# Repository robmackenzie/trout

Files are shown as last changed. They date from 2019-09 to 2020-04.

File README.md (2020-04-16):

# Magic Trout Imaginarium V2
ESP8266 based controller for talking/singing trout.

This is a fork of a previous project that ran the same idea off a raspberry pi controller. Here we have a perfboard with an mp3 module and the motor controllers all in one.

The board takes 12v, and can be run off pretty much any 12v battery or power source. It draws 1 amp at max load when talking.

The 
# Structure
## Docs
I've included all the PDFs for the components on the board, except for a generic 5v regulator that powers the hbridge and the audio chip.

## Audio/sd_card
The audio files which are included on the SD card on the mp3 player inside the control box. More can be added, which will be randomly chosen when the button is pushed.
Files must be be contained in SD card in specific structure.
The welcome file must be in the root directory, and be the first file coppied
onto the SD card. If you want to replace it, you must delete all other files
first. The files to be randomly chosen at a button push must be in a folder
called "02"
Example below:
/001.mp3 *Welcome file
/02/001.mp3 *Random file
/02/002.mp3 *Random file
/02/003.mp3 *Random file

## lib
External libraries that are used to control the trout, such as timing and mp3 player control. These are automatically pulled in with platform.io

## src
Source code that controls the fish. Inside the main.cpp file you can find adjustable variables to control timings of the fish.

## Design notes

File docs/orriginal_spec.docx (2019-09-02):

# Fortune Telling Fish.

A weird fish oracle that you can ask your fortune!

Trout which answers questions similar to a magic eight ball. Using a microcontroller similar to an Arduino called a propeller we can store many minutes of audio on an SD card and record the responses and lipsync the fish so that the responses and fish mouth match.

Possible additional features

- respond to sound with microphone. It would be ideal to be able to understand human speech but without a semi-powerful computer and internet, this would be difficult. If we wanted to use an internet connected Raspberry Pi this could be possible to some degree. For the standalone micro version, it would just respond to audio volume mainly and come to life and/or say something.
- Remote operation. Puppet the fish remotely! Using a camera and a microphone to give you fish telepresence. We would use a voice changer to make the fish voice. Essentially a puppet, it could be quite entertaining.
- Ask a question then touch the fish...or like press a button or touch a crystal ball....something that would trigger the response easier. Easier design
- wearable version! Mounted on your body in some form. Details to be determined. Need some sketches. (even crude is fine)

Mounting

Zee wants it to be sort of mounted in a tri-fold cabinet so when you approach it like a space you are entering...maybe install some lights. (Need illustration - crude is fine. I can fix them up)

Dates: End of June or June 11th for Maker Faire.

Fish measurements.

Nose to tail 29 cm

Dorsal fin tallest point 12 cm

Tail fin 8.5 cm

Kinda like this is s tent although this pic doesn't have the button

In a tent like A circus sideshow

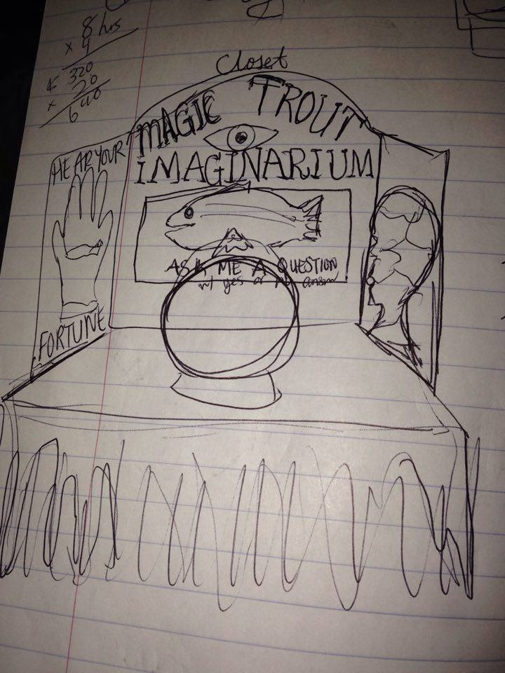
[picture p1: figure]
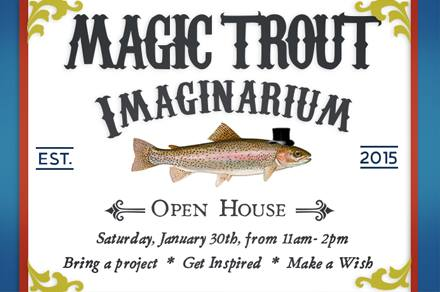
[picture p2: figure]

The button could be On the plaque.. I could make a new plaque if the one that it comes on isn't big enough, I could router out a place to fit the electronics in the back

New feature. Coin operation! Something like the following unit taking a loonie?

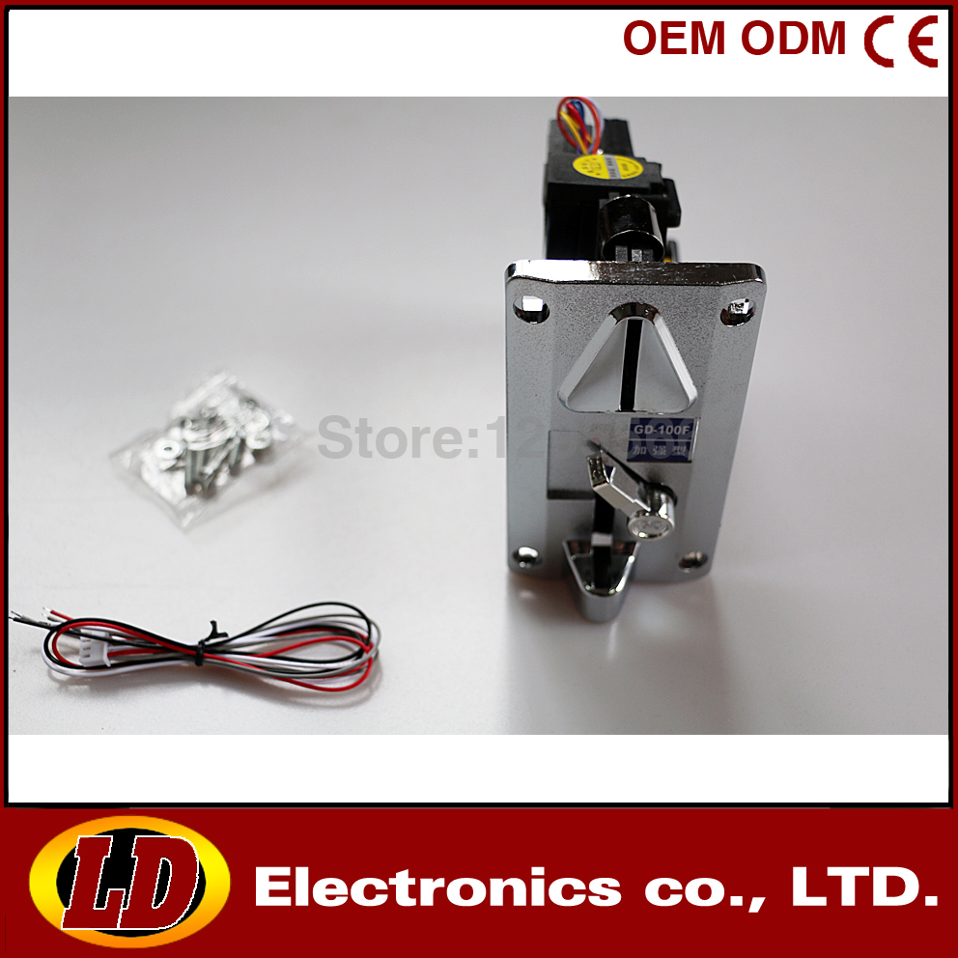
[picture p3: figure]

SAMPLE IMAGES

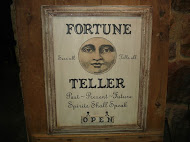
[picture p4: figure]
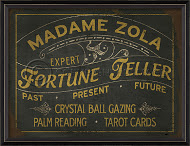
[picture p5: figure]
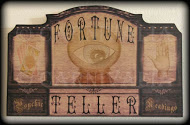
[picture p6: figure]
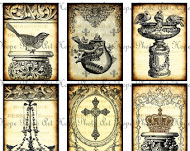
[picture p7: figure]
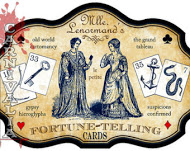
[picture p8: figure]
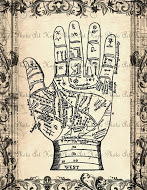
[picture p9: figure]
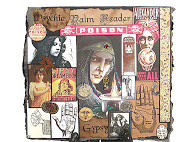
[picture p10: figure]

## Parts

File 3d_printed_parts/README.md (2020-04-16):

# Trout 3d parts. 

The control box is the blue box which holds the perfboard and the resistors/wiring.
The connector is the little box that holds the connector, epoxied to the back of the trout.

Both these were designed in onShape. Here are public links to edit them.

Connector:
https://cad.onshape.com/documents/b16a1caab3e71b815caed591/w/0d1a3dc45dbcdb8519a24483/e/a3f8292bcb0fa2a3ff2797b2

Control box:
https://cad.onshape.com/documents/043c3a39a97f1b821955c03b/w/93248ce4fd4cac564a92f262/e/5e92760116738c28ccedb01d

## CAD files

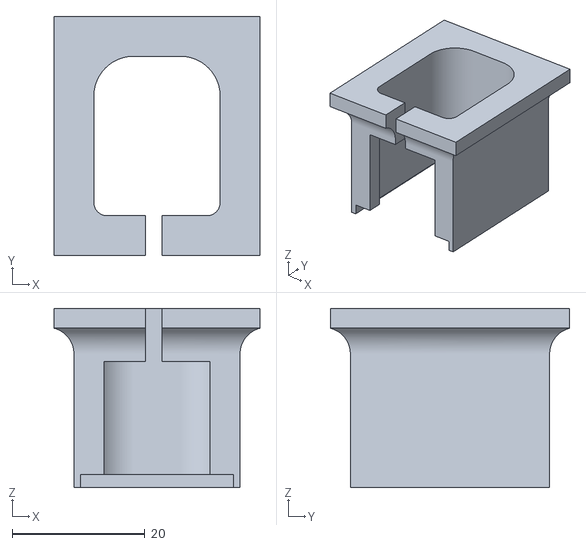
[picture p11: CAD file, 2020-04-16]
3d_printed_parts/Trout Connector - Bottom.stl
31.0 x 36.0 x 27.0

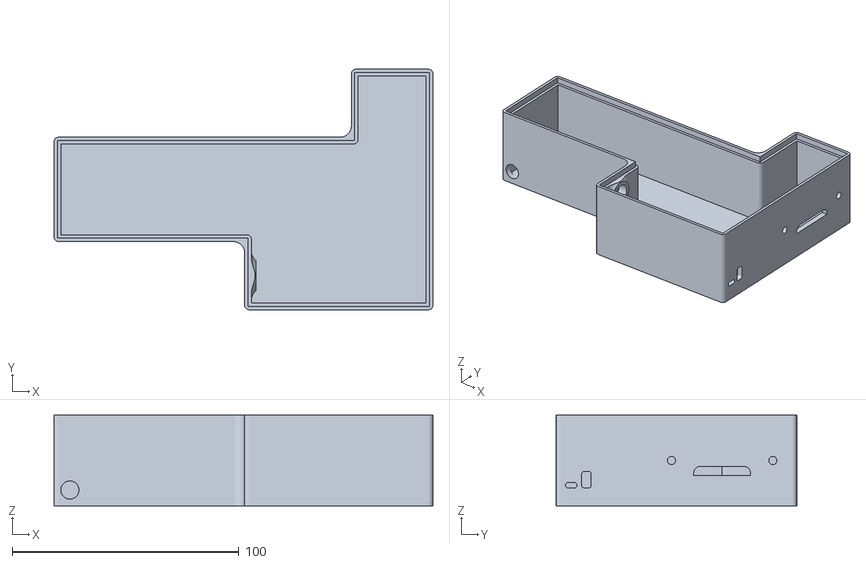
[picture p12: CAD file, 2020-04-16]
3d_printed_parts/Trout Control - Bottom.stl
167.0 x 106.0 x 40.0

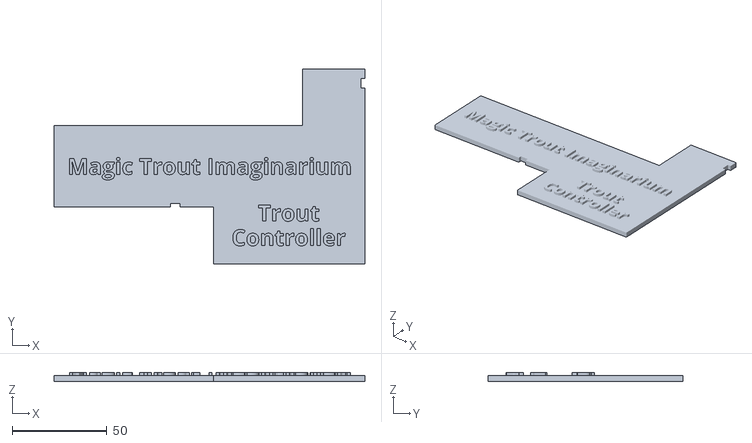
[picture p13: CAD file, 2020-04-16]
3d_printed_parts/Trout Control - Top.stl
164.0 x 103.0 x 4.50

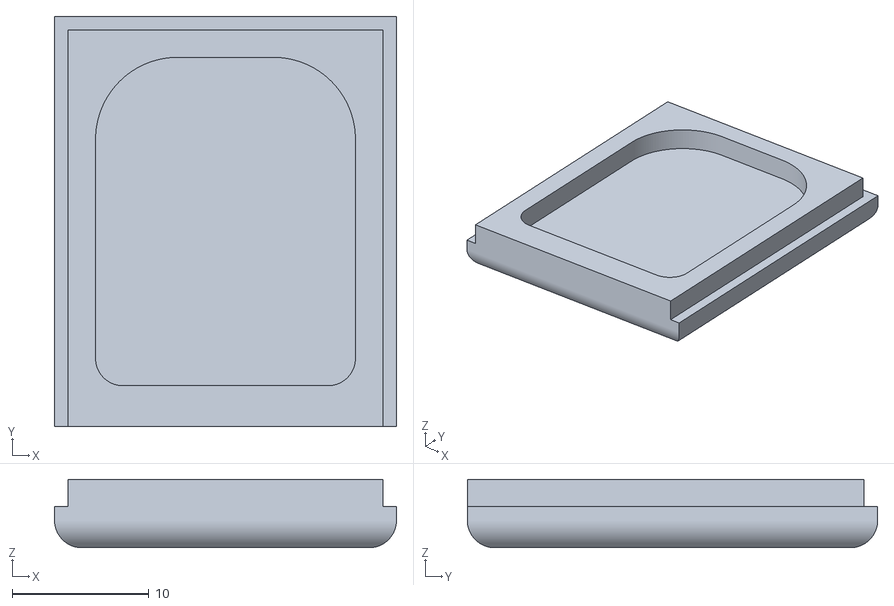
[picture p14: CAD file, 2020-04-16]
3d_printed_parts/Trout Connector - Top.stl
25.0 x 30.0 x 5.00

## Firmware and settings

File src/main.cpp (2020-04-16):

// Files must be be contained in SD card in specific structure.
// The welcome file must be in the root directory, and be the first file coppied
// onto the SD card. If you want to replace it, you must delete all other files
// first. The files to be randomly chosen at a button push must be in a folder
// called "02" 
// Example below:
// /001.mp3 *Welcome file
// /02/001.mp3 *Random file 
// /02/002.mp3 *Random file 
// /02/003.mp3 *Random file 

// Below are some variables that can be easily modified to change the behaviour of the fish
#define SECONDS_BETWEEN_WELCOME_CLIPS_MIN 300
#define SECONDS_BETWEEN_WELCOME_CLIPS_MAX 400

#define SECONDS_BETWEEN_IDLE_TAIL_FLAPS_MIN 5
#define SECONDS_BETWEEN_IDLE_TAIL_FLAPS_MAX 55

#define IDLE_TAIL_FLAP_EXTEND_LENGTH_MS_MIN 200
#define IDLE_TAIL_FLAP_EXTEND_LENGTH_MS_MAX 1000

#define TAIL_RETURN_TIME 200

#define TALKING_MOUTH_EXTEND_LENGTH_MS_MIN 100
#define TALKING_MOUTH_EXTEND_LENGTH_MS_MAX 400

#define TALKING_MOUTH_RETRACT_LENGTH_MS_MIN 50
#define TALKING_MOUTH_RETRACT_LENGTH_MS_MAX 250

#define TALKING_TAIL_FLAP_EXTEND_LENGTH_MS_MIN 200
#define TALKING_TAIL_FLAP_EXTEND_LENGTH_MS_MAX 400

#define TALKING_TAIL_FLAP_RETRACT_LENGTH_MS_MIN 150
#define TALKING_TAIL_FLAP_RETRACT_LENGTH_MS_MAX 250

#define HEAD_EXTEND_TIME_MS 300
#define HEAD_RETRACT_TIME_MS 220

#define MP3_TIMEOUT_TIME_MS 4000
#define VOLUME 18 // Set volume value (0~30)

// Input pin
#define button_pin 16

// Motor pins
#define head_move_in_pin 13
#define head_move_out_pin 15
#define mouth_move_pin 12
#define tail_move_pin 14

// Following defined in mp3.cpp. Listed here for visibility of pins used
//#define software_tx_pin 4
//#define software_rx_pin  5

// clang-format off
/*
FSM States:
  A - Resting, waiting for button push. Will time out to play welcome message,
      flipping tail a bit randomly. 
  B - Activated, moving head out 
  C - Playing sound, moving lips and tail 
  D - Moving head back
*/
// clang-format on

// Because we still rely on the arduino env.
#include <Arduino.h>

// Timer to make pulsing tail/lip easier
#include <AsyncDelay.h>
enum motor_status
{
  RESTING,
  EXTENDING,
  RETRACTING
};
enum head_status
{
  H_RESTING,
  H_EXTENDING,
  H_RETRACTING,
  H_BRAKING
}; 
AsyncDelay mouth_delay;
AsyncDelay tail_delay;
uint8_t mouth_status = RESTING;
uint8_t tail_status = RESTING;

// Our Libs
#include "mp3.h"

// Finite State Machine lib
#include <FunctionFSM.h>

bool button_triggered = false; // This track button 
enum Trigger
{
  TOGGLE_SWITCH,
  MP3_FINISHED
};

void
head_motor(head_status status)
{
  switch (status) {
    case H_RESTING: {
      Serial.println("Entering head resting");
      digitalWrite(head_move_out_pin, LOW);
      digitalWrite(head_move_in_pin, LOW);
    }
    break;

    case H_EXTENDING: {
      Serial.println("Entering head extending");
      digitalWrite(head_move_out_pin, HIGH);
      digitalWrite(head_move_in_pin, LOW);
    }
    break;

    case H_RETRACTING: {
      Serial.println("Entering head retracting");
      digitalWrite(head_move_out_pin, LOW);
      digitalWrite(head_move_in_pin, HIGH);
    }
    break;

    case H_BRAKING: {
      Serial.println("Entering head braking");
      digitalWrite(head_move_out_pin, HIGH);
      digitalWrite(head_move_in_pin, HIGH);
    }
    break;

  }
}
// fsm state functions
void
A_start()
{
  Serial.println("Entering State A");
  tail_status = RETRACTING;
  tail_delay.start(random(SECONDS_BETWEEN_IDLE_TAIL_FLAPS_MIN,SECONDS_BETWEEN_IDLE_TAIL_FLAPS_MAX)*1000, AsyncDelay::MILLIS);
}
void
A_loop()
{
  if (tail_status == RESTING) {
    tail_delay.start(random(IDLE_TAIL_FLAP_EXTEND_LENGTH_MS_MIN, IDLE_TAIL_FLAP_EXTEND_LENGTH_MS_MAX), AsyncDelay::MILLIS);
    digitalWrite(tail_move_pin, HIGH);
    tail_status = EXTENDING;
  } else if (tail_status == EXTENDING && tail_delay.isExpired()) {
    tail_delay.start(random(SECONDS_BETWEEN_IDLE_TAIL_FLAPS_MIN,SECONDS_BETWEEN_IDLE_TAIL_FLAPS_MAX)*1000, AsyncDelay::MILLIS);
    digitalWrite(tail_move_pin, LOW);
    tail_status = RETRACTING;
  } else if (tail_status == RETRACTING && tail_delay.isExpired()) {
    tail_status = RESTING;
  }
}

void
B_start()
{
  Serial.println("Entering State B");
  head_motor(H_EXTENDING);
}
void
B_stop()
{
  Serial.println("Leaving State B");
  //head_motor(H_BRAKING);  
}

void
C_trigger(); // Defined later, declared here for use in C_start

void
C_start()
{
  Serial.println("Entering State C");
  
  digitalWrite(tail_move_pin, HIGH);
  delay(random(TALKING_TAIL_FLAP_EXTEND_LENGTH_MS_MIN, TALKING_TAIL_FLAP_EXTEND_LENGTH_MS_MAX));
  digitalWrite(tail_move_pin, LOW);
  delay(random(TALKING_TAIL_FLAP_RETRACT_LENGTH_MS_MAX,TALKING_TAIL_FLAP_RETRACT_LENGTH_MS_MAX));
  digitalWrite(tail_move_pin, HIGH);
  delay(random(TALKING_TAIL_FLAP_EXTEND_LENGTH_MS_MIN, TALKING_TAIL_FLAP_EXTEND_LENGTH_MS_MAX));
  digitalWrite(tail_move_pin, LOW);
  delay(random(TALKING_TAIL_FLAP_RETRACT_LENGTH_MS_MAX,TALKING_TAIL_FLAP_RETRACT_LENGTH_MS_MAX));
  tail_status = RESTING;
  
  if (button_triggered) {
    mp3.play_random(&C_trigger);
  } else {
    mp3.play_welcome(&C_trigger);
  }
}

void
C_loop()
{
  // Move mouth and tail.
  if (mouth_status == RESTING) {
    mouth_delay.start(random(TALKING_MOUTH_EXTEND_LENGTH_MS_MIN,TALKING_MOUTH_EXTEND_LENGTH_MS_MAX), AsyncDelay::MILLIS);
    digitalWrite(mouth_move_pin, HIGH);
    mouth_status = EXTENDING;
  } else if (mouth_status == EXTENDING && mouth_delay.isExpired()) {
    mouth_delay.start(random(TALKING_MOUTH_RETRACT_LENGTH_MS_MIN,TALKING_MOUTH_RETRACT_LENGTH_MS_MIN), AsyncDelay::MILLIS);
    digitalWrite(mouth_move_pin, LOW);
    mouth_status = RETRACTING;
  } else if (mouth_status == RETRACTING && mouth_delay.isExpired()) {
    mouth_status = RESTING;
  }

  if (tail_status == RESTING) {
    tail_delay.start(random(TALKING_TAIL_FLAP_EXTEND_LENGTH_MS_MIN, TALKING_TAIL_FLAP_EXTEND_LENGTH_MS_MAX), AsyncDelay::MILLIS);
    digitalWrite(tail_move_pin, HIGH);
    tail_status = EXTENDING;
  } else if (tail_status == EXTENDING && tail_delay.isExpired()) {
    tail_delay.start(random(TALKING_TAIL_FLAP_RETRACT_LENGTH_MS_MAX,TALKING_TAIL_FLAP_RETRACT_LENGTH_MS_MAX), AsyncDelay::MILLIS);
    digitalWrite(tail_move_pin, LOW);
    tail_status = RETRACTING;
  } else if (tail_status == RETRACTING && tail_delay.isExpired()) {
    tail_status = RESTING;
  }
}

void
C_stop()
{
  digitalWrite(tail_move_pin, LOW);
  digitalWrite(mouth_move_pin, LOW);
}
void
D_start()
{
  Serial.println("Entering State D");
  head_motor(H_RETRACTING);
}

void
D_stop()
{
  Serial.println("Leaving State D");
  head_motor(H_BRAKING);
  button_triggered=false;
}

// fsm states (initialise in MyClass constructor)
FunctionState state_A(&A_start, &A_loop, nullptr);
FunctionState state_B(&B_start, nullptr, &B_stop);
FunctionState state_C(&C_start, &C_loop, &C_stop);
FunctionState state_D(&D_start, nullptr, &D_stop);

// fsm (initialise with MyClass constructor)
FunctionFsm fsm(&state_B);

void
C_trigger()
{
  Serial.println("Triggering end of state C");
  fsm.trigger(MP3_FINISHED);
};

void
setup()
{
  Serial.begin(115200);
  Serial.flush();
  Serial.println();
  Serial.println("Trout Control V2");
  Serial.println();
  Serial.flush(); // Get serial all nice and ready, with some new lines.
  mp3.setup();  // Initiallize mp3 player, sets up a link, will loop, forcing WDT reset if fails.
  //TODO Maybe put in a way of telling what's wrong with the system on fails
  mp3.set_volume(VOLUME);
  
  // Set up in/out pins
  pinMode(button_pin, INPUT);
  int outputs[4] = {
    head_move_in_pin, head_move_out_pin, mouth_move_pin, tail_move_pin
  };
  for (int i = 0; i < 4; i++) {
    pinMode(outputs[i], OUTPUT);
    digitalWrite(outputs[i], LOW);
  }
  // //Cycle motors to test.
  // for (int i = 0; i < 4; i++) {
  //   digitalWrite(outputs[i], HIGH);
  //   delay(500);
  //   digitalWrite(outputs[i], LOW);
  // }

  // init fsm
  fsm.add_timed_transition(
    &state_A,
    &state_B,
    random(SECONDS_BETWEEN_WELCOME_CLIPS_MIN,SECONDS_BETWEEN_WELCOME_CLIPS_MAX) * 1000, // 1000 ms in a second
    nullptr); // After timeout, have fish say welcome message.
  fsm.add_transition(&state_A,
                     &state_B,
                     TOGGLE_SWITCH,
                     nullptr); // Transition on button push or welcome timeout
  fsm.add_timed_transition(&state_B,
                           &state_C,
                           HEAD_EXTEND_TIME_MS,
                           nullptr); // Wait for head to move out
  fsm.add_timed_transition(
    &state_C,
    &state_D,
    MP3_TIMEOUT_TIME_MS, // Max length of any audio file
    nullptr); // Timeout in case something went wrong with the mp3 callback
  fsm.add_transition(&state_C,
                     &state_D,
                     MP3_FINISHED,
                     nullptr); // Transition on MP3 finished playing.
  fsm.add_timed_transition(&state_D,
                           &state_A,
                           HEAD_RETRACT_TIME_MS,
                           nullptr); // Wait for head to move back
}

void loop()
{
  fsm.run_machine(); // Do Finite State Machine tasks
  mp3.loop(); // Do anything with talking to the MP3 Module

  // Check the button push. Could be moved to a interrupt, but no real need. This works well.
  if (fsm.is_in_state(state_A) && !button_triggered && !digitalRead(button_pin)) {
    Serial.println("Button Triggered");
    button_triggered = true;
    fsm.trigger(TOGGLE_SWITCH);
  }
}

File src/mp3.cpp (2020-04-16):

#define software_tx_pin 4
#define software_rx_pin  5

#include "Arduino.h"
#include "SoftwareSerial.h"
#include "DFRobotDFPlayerMini.h"
#include "mp3.h"

typedef void (*voidFuncPtr)(void); // Needed to track callback function
void do_nothing() {};
voidFuncPtr callback_function = do_nothing;
bool callback_needed = false;

SoftwareSerial mySoftwareSerial(software_rx_pin, software_tx_pin); // RX, TX
DFRobotDFPlayerMini myDFPlayer;
int num_random_files;
void printDetail(uint8_t type, int value);


sclass::sclass() {
}

void sclass::setup() {
  {
    mySoftwareSerial.begin(9600);
    Serial.println();
    Serial.println(F("Initializing DFPlayer ... (May take 3~5 seconds)"));
    if (!myDFPlayer.begin(mySoftwareSerial)) {  //Use softwareSerial to communicate with mp3.
      Serial.println(F("Unable to begin:"));
      Serial.println(F("1.Please recheck the connection!"));
      Serial.println(F("2.Please insert the SD card!"));
      while (true);
    }
    Serial.println(F("DFPlayer Mini online."));

    myDFPlayer.setTimeOut(500); //Set serial communictaion time out 500ms

    //----Set volume----
    myDFPlayer.volume(20);  //Set volume value (0~30).
    num_random_files = myDFPlayer.readFileCountsInFolder(2); //Read total of random files in folder "/02/"
    randomSeed(analogRead(0));
  }
}

void sclass::loop() {
  if (myDFPlayer.available()) {
    uint8_t type = myDFPlayer.readType();
    int value = myDFPlayer.read();
    if (type == DFPlayerPlayFinished && callback_needed) {
      callback_needed = false;
      callback_function();
    } else if (type != DFPlayerPlayFinished) {
      printDetail(type, value); //Print the detail message from DFPlayer to handle different errors and states.
    }
  }
}

void sclass::play_welcome(void (*userFunc)(void)) {
  callback_function = userFunc;
  callback_needed = true;
  play_welcome();
}
void sclass::play_random(void (*userFunc)(void)) {
  callback_function = userFunc;
  callback_needed = true;
  play_random();
}
void sclass::play_welcome() {
  myDFPlayer.play(1);
}
void sclass::play_random() {
  myDFPlayer.playFolder(2, random(num_random_files) + 1);
}

void sclass::set_volume(u_int volume) {
    myDFPlayer.volume(volume);  //Set volume value (0~30).
}


sclass mp3 = sclass();

void printDetail(uint8_t type, int value) {
  switch (type) {
    case TimeOut:
      Serial.println(F("Time Out!"));
      break;
    case WrongStack:
      Serial.println(F("Stack Wrong!"));
      break;
    case DFPlayerCardInserted:
      Serial.println(F("Card Inserted!"));
      break;
    case DFPlayerCardRemoved:
      Serial.println(F("Card Removed!"));
      break;
    case DFPlayerCardOnline:
      Serial.println(F("Card Online!"));
      break;
    case DFPlayerUSBInserted:
      Serial.println("USB Inserted!");
      break;
    case DFPlayerUSBRemoved:
      Serial.println("USB Removed!");
      break;
    case DFPlayerPlayFinished:
      Serial.print(F("Number:"));
      Serial.print(value);
      Serial.println(F(" Play Finished!"));
      break;
    case DFPlayerError:
      Serial.print(F("DFPlayerError:"));
      switch (value) {
        case Busy:
          Serial.println(F("Card not found"));
          break;
        case Sleeping:
          Serial.println(F("Sleeping"));
          break;
        case SerialWrongStack:
          Serial.println(F("Get Wrong Stack"));
          break;
        case CheckSumNotMatch:
          Serial.println(F("Check Sum Not Match"));
          break;
        case FileIndexOut:
          Serial.println(F("File Index Out of Bound"));
          break;
        case FileMismatch:
          Serial.println(F("Cannot Find File"));
          break;
        case Advertise:
          Serial.println(F("In Advertise"));
          break;
        default:
          break;
      }
      break;
    default:
      break;
  }

}

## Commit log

2019-09-02 Removed python version, added firmware for ESP version, on arduino IDE
2019-09-05 removed motor file, can all be driven off main
2019-09-06 Added asyncDelay lib, fixed syntax bugs in code
    [main.cpp]
2020-04-16 Final v2, shipping. Moved all numbers into defs, added volume, fixed bugs with control fallthrough. Soak tested
    [main.cpp, mp3.cpp]
